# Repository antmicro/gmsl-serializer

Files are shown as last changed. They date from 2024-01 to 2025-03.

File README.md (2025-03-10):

# GMSL Serializer Board

Copyright (c) 2023-2025 [Antmicro](https://www.antmicro.com)

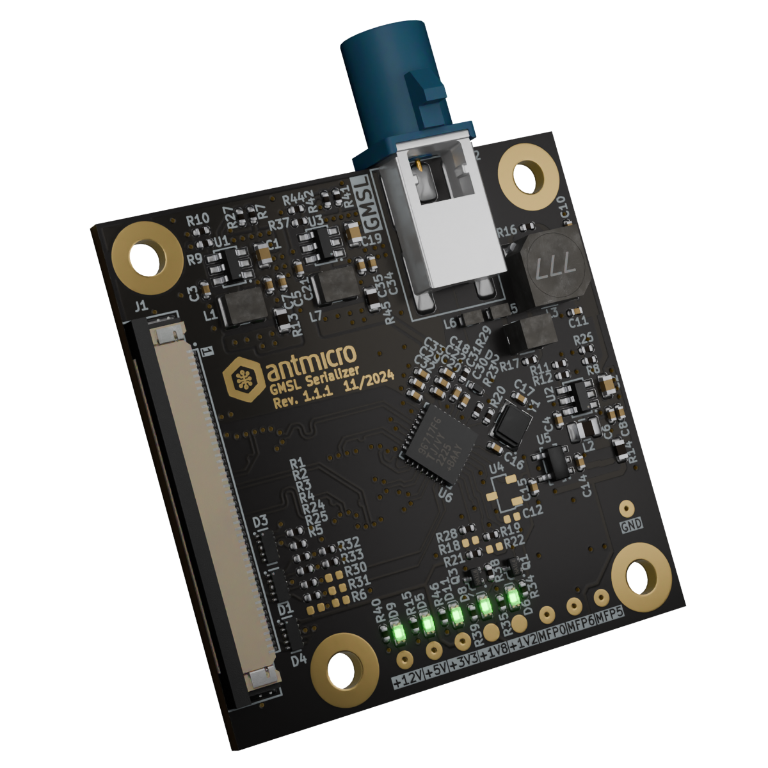
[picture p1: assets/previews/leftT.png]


## Overview

This project contains open hardware design files for the GMSL Serializer Board.
This board accepts MIPI CSI-2 signals from Antmicro's 50-pin FFC video interface and transmits the video data over GMSL2.
The GMSL Serializer Board is powered over GMSL coaxial cable.

The design files were prepared in KiCad 8.

## Key features

* Input: 4-lane MIPI CSI-2 interface on a 50-pin Antmicro Dual Camera connector
* Output: GMSL2 interface exposed on a FAKRA connector
* PoC filter for sinking power from the GMSL coaxial cable

## Project structure

The main project directory contains KiCad PCB project files, a LICENSE, and a README.
The remaining files are stored in the following directories:

* `doc` - contains schematics
* `assets` - contains visual assets for showcasing the board on Antmicro [Open Hardware Portal](https://openhardware.antmicro.com)

## Licensing

This project is published under the [Apache-2.0](LICENSE) license.

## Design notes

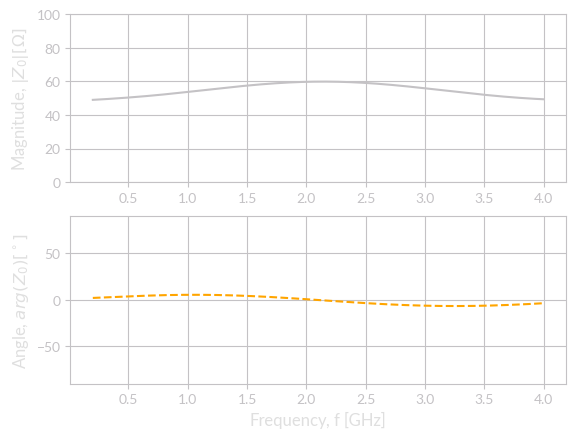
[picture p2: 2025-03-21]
assets/si/GMSL_Connector_SIO_P/Z_1.png

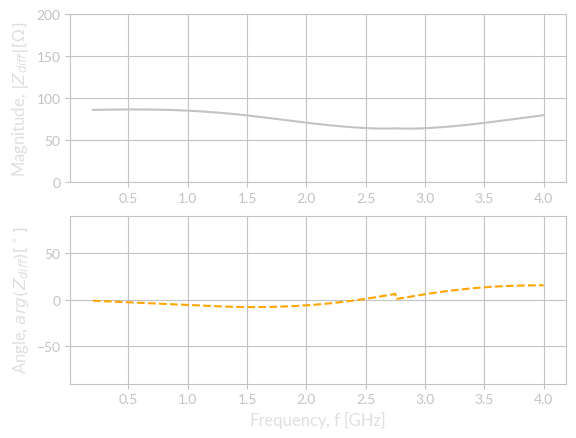
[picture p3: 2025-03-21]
assets/si/CSI_Connector_CSI.D1_Diff/Z_diff.png

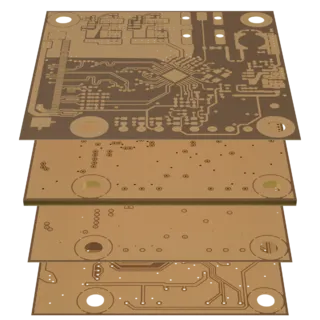
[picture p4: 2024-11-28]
assets/previews/layer1_thumbnail.webp

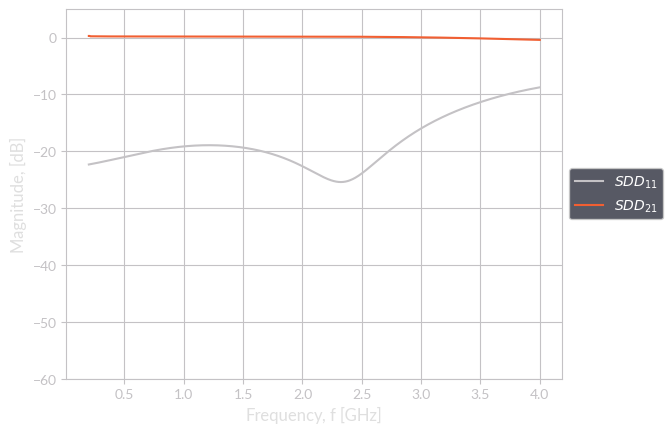
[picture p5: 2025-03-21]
assets/si/CSI_Connector_CSI.D0_Diff/SDD_Diff.png

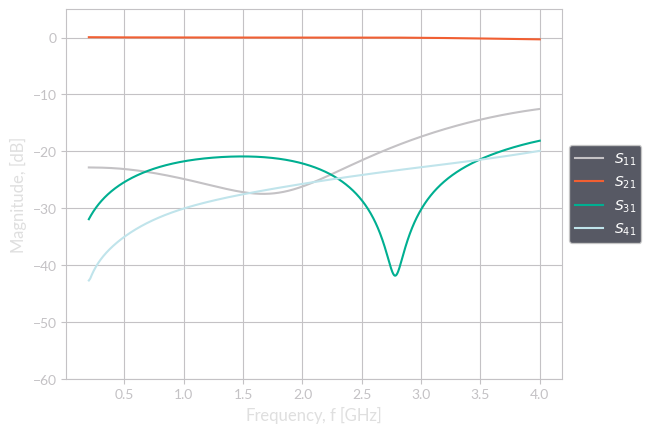
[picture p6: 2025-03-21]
assets/si/CSI_Connector_CSI.D0_Diff/S_x1.png

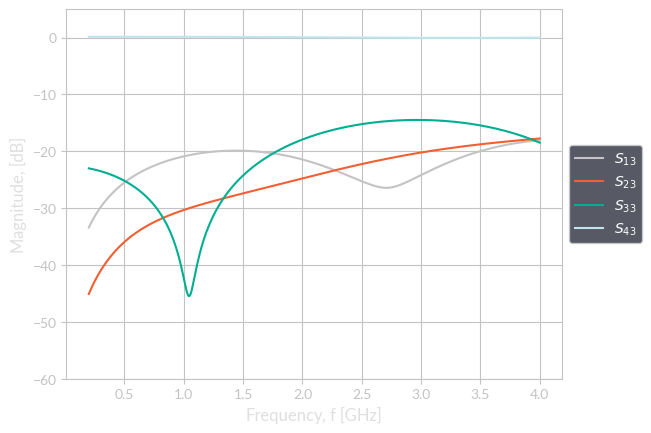
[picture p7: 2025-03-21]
assets/si/CSI_Connector_CSI.CLK_Diff/S_x3.png

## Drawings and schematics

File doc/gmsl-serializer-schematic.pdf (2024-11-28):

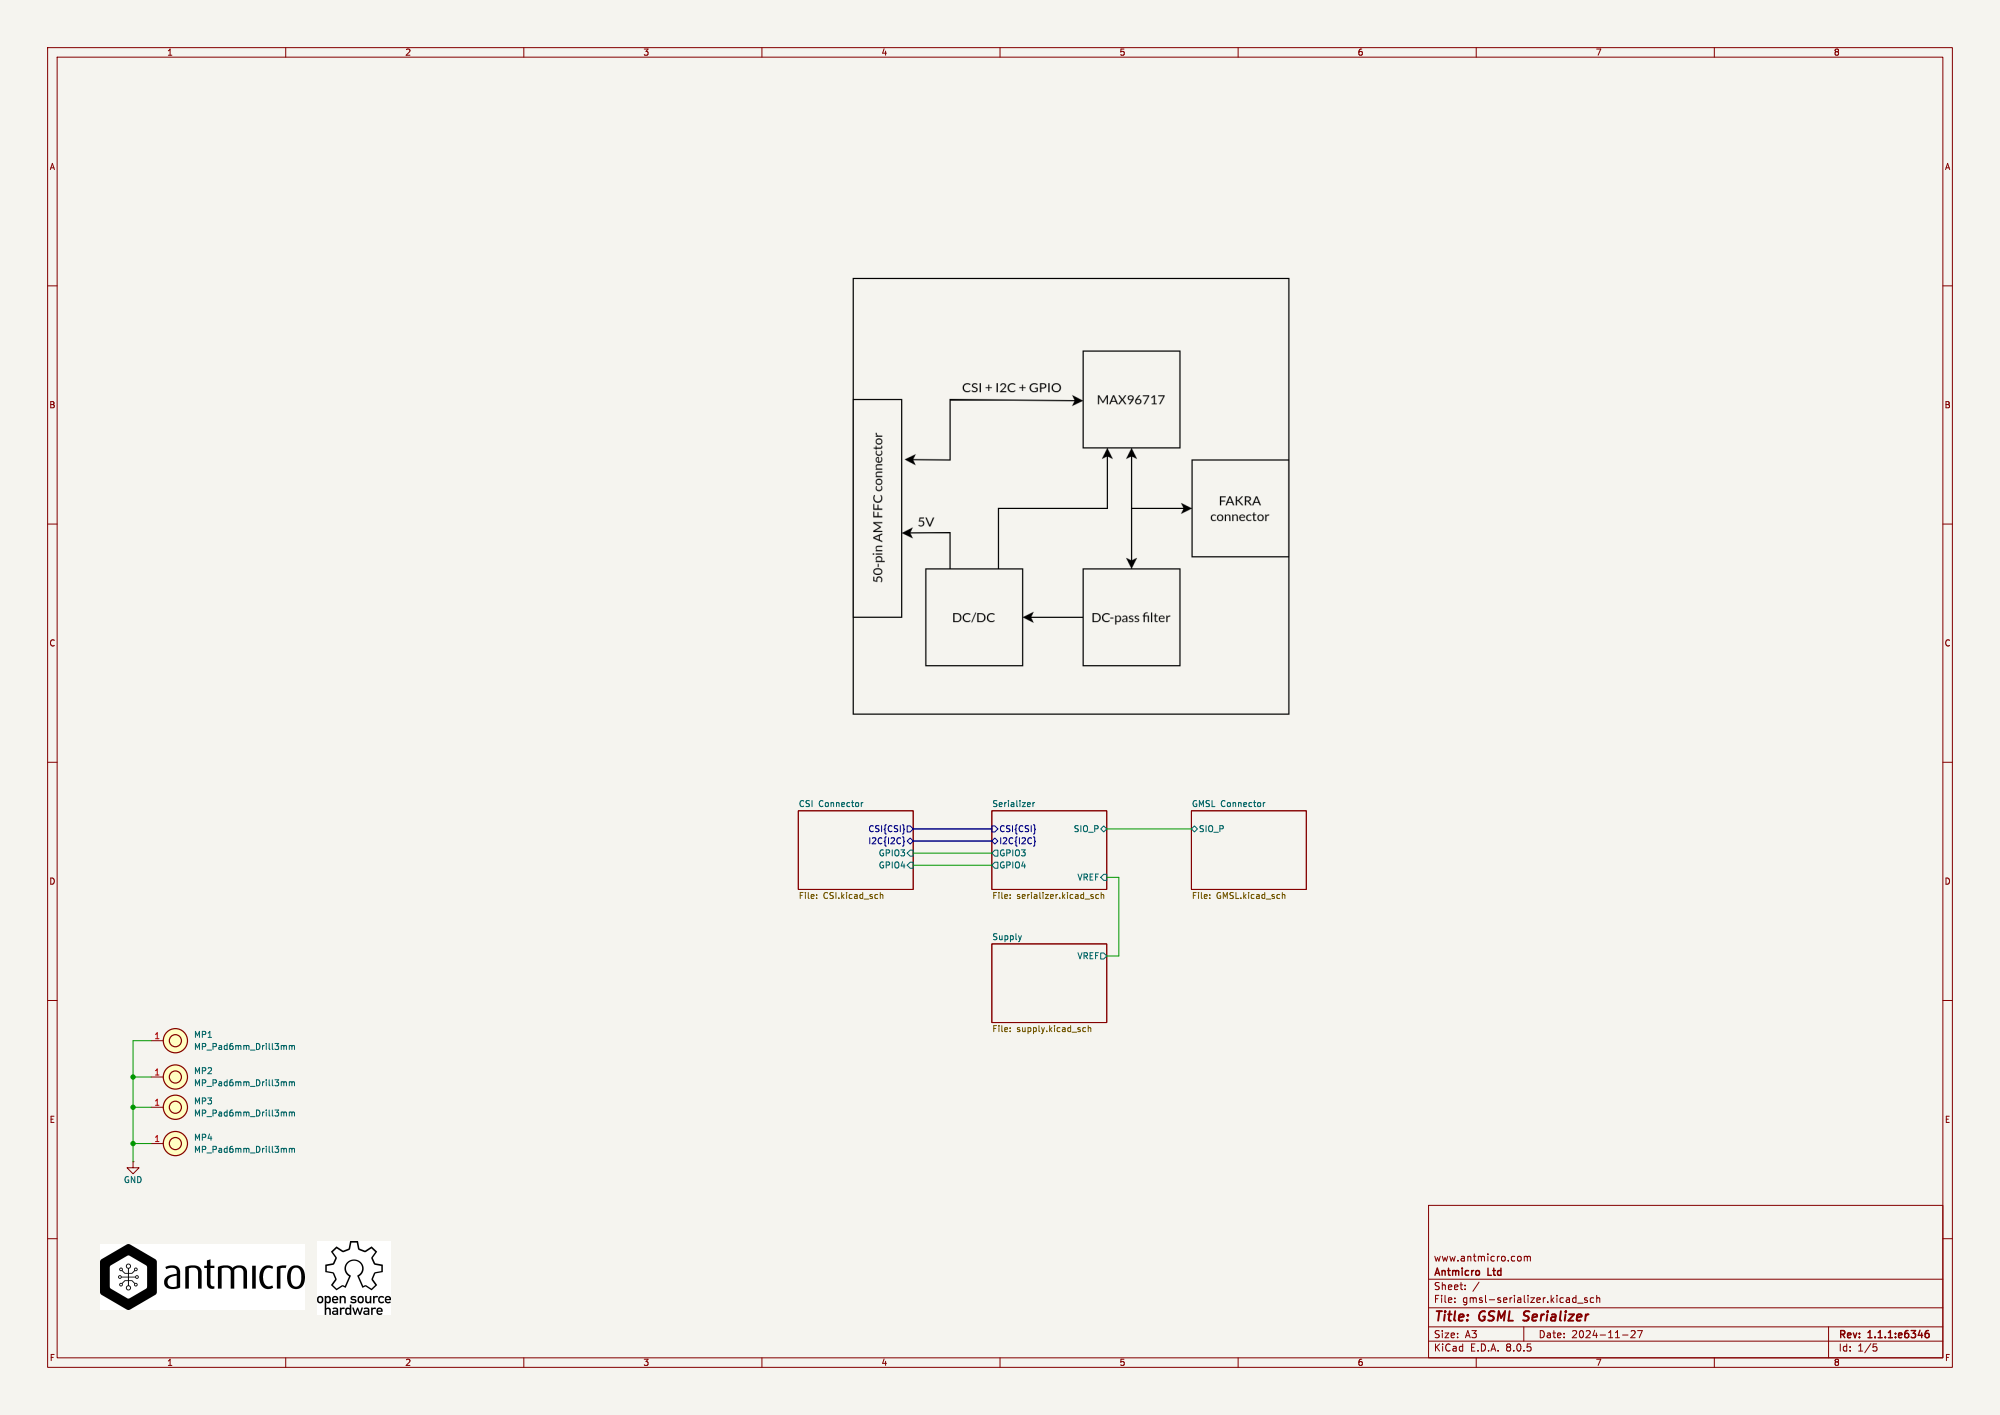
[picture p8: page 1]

I2C{I2C} GPIO4 GPIO3 CSI Connector File: CSI.kicad_sch

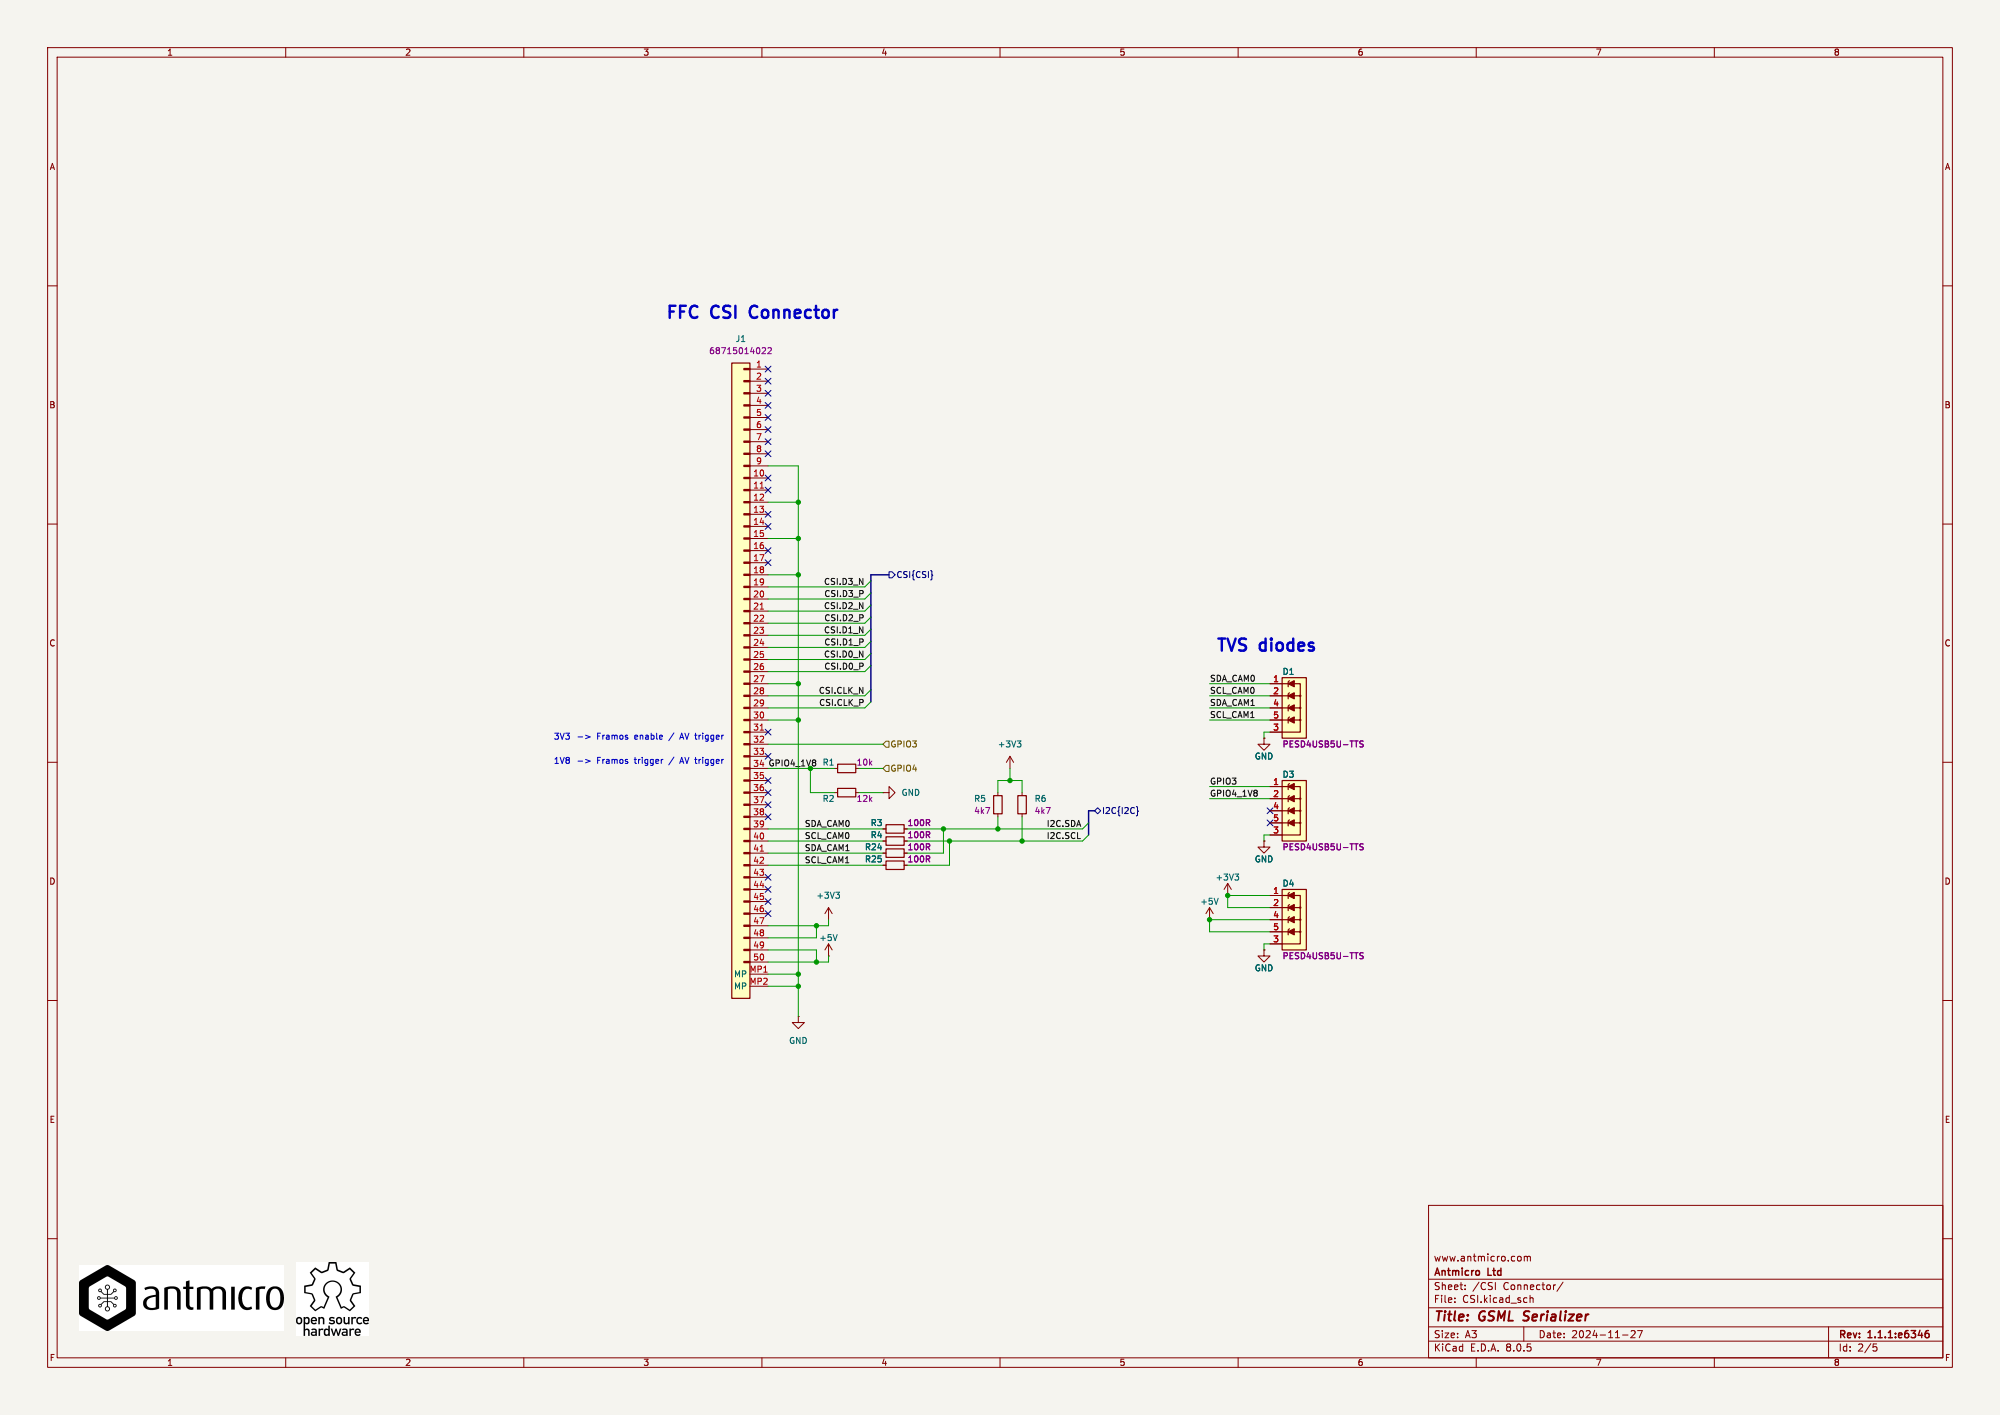
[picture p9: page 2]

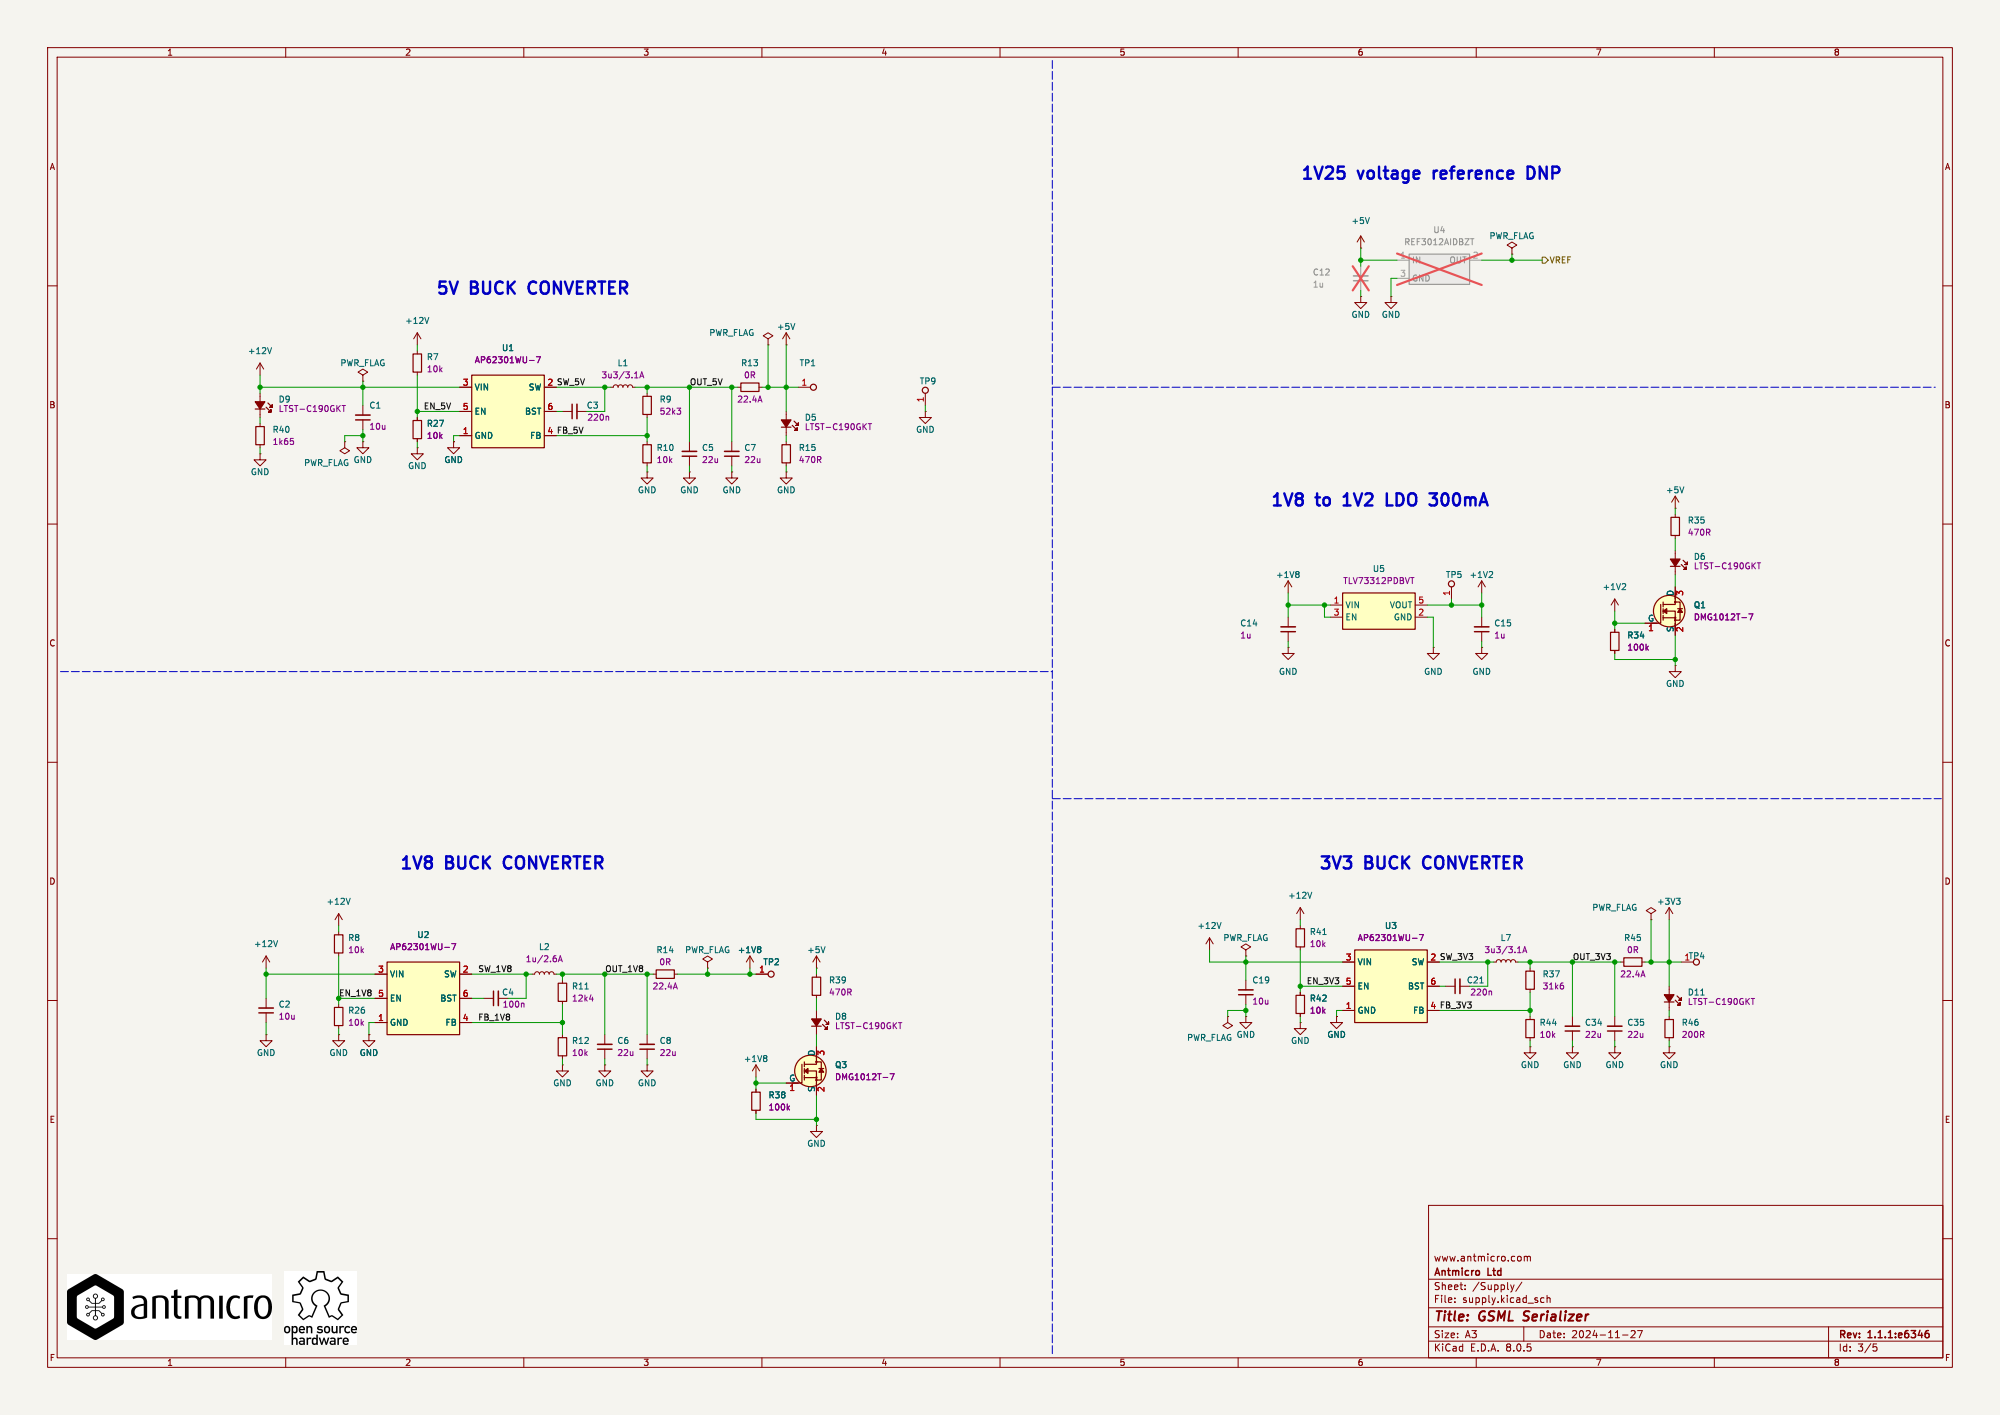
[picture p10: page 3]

1 TP5 +1V2 VIN 1 GND 2 EN 3 VOUT 5 U5 TLV73312PDBVT GND

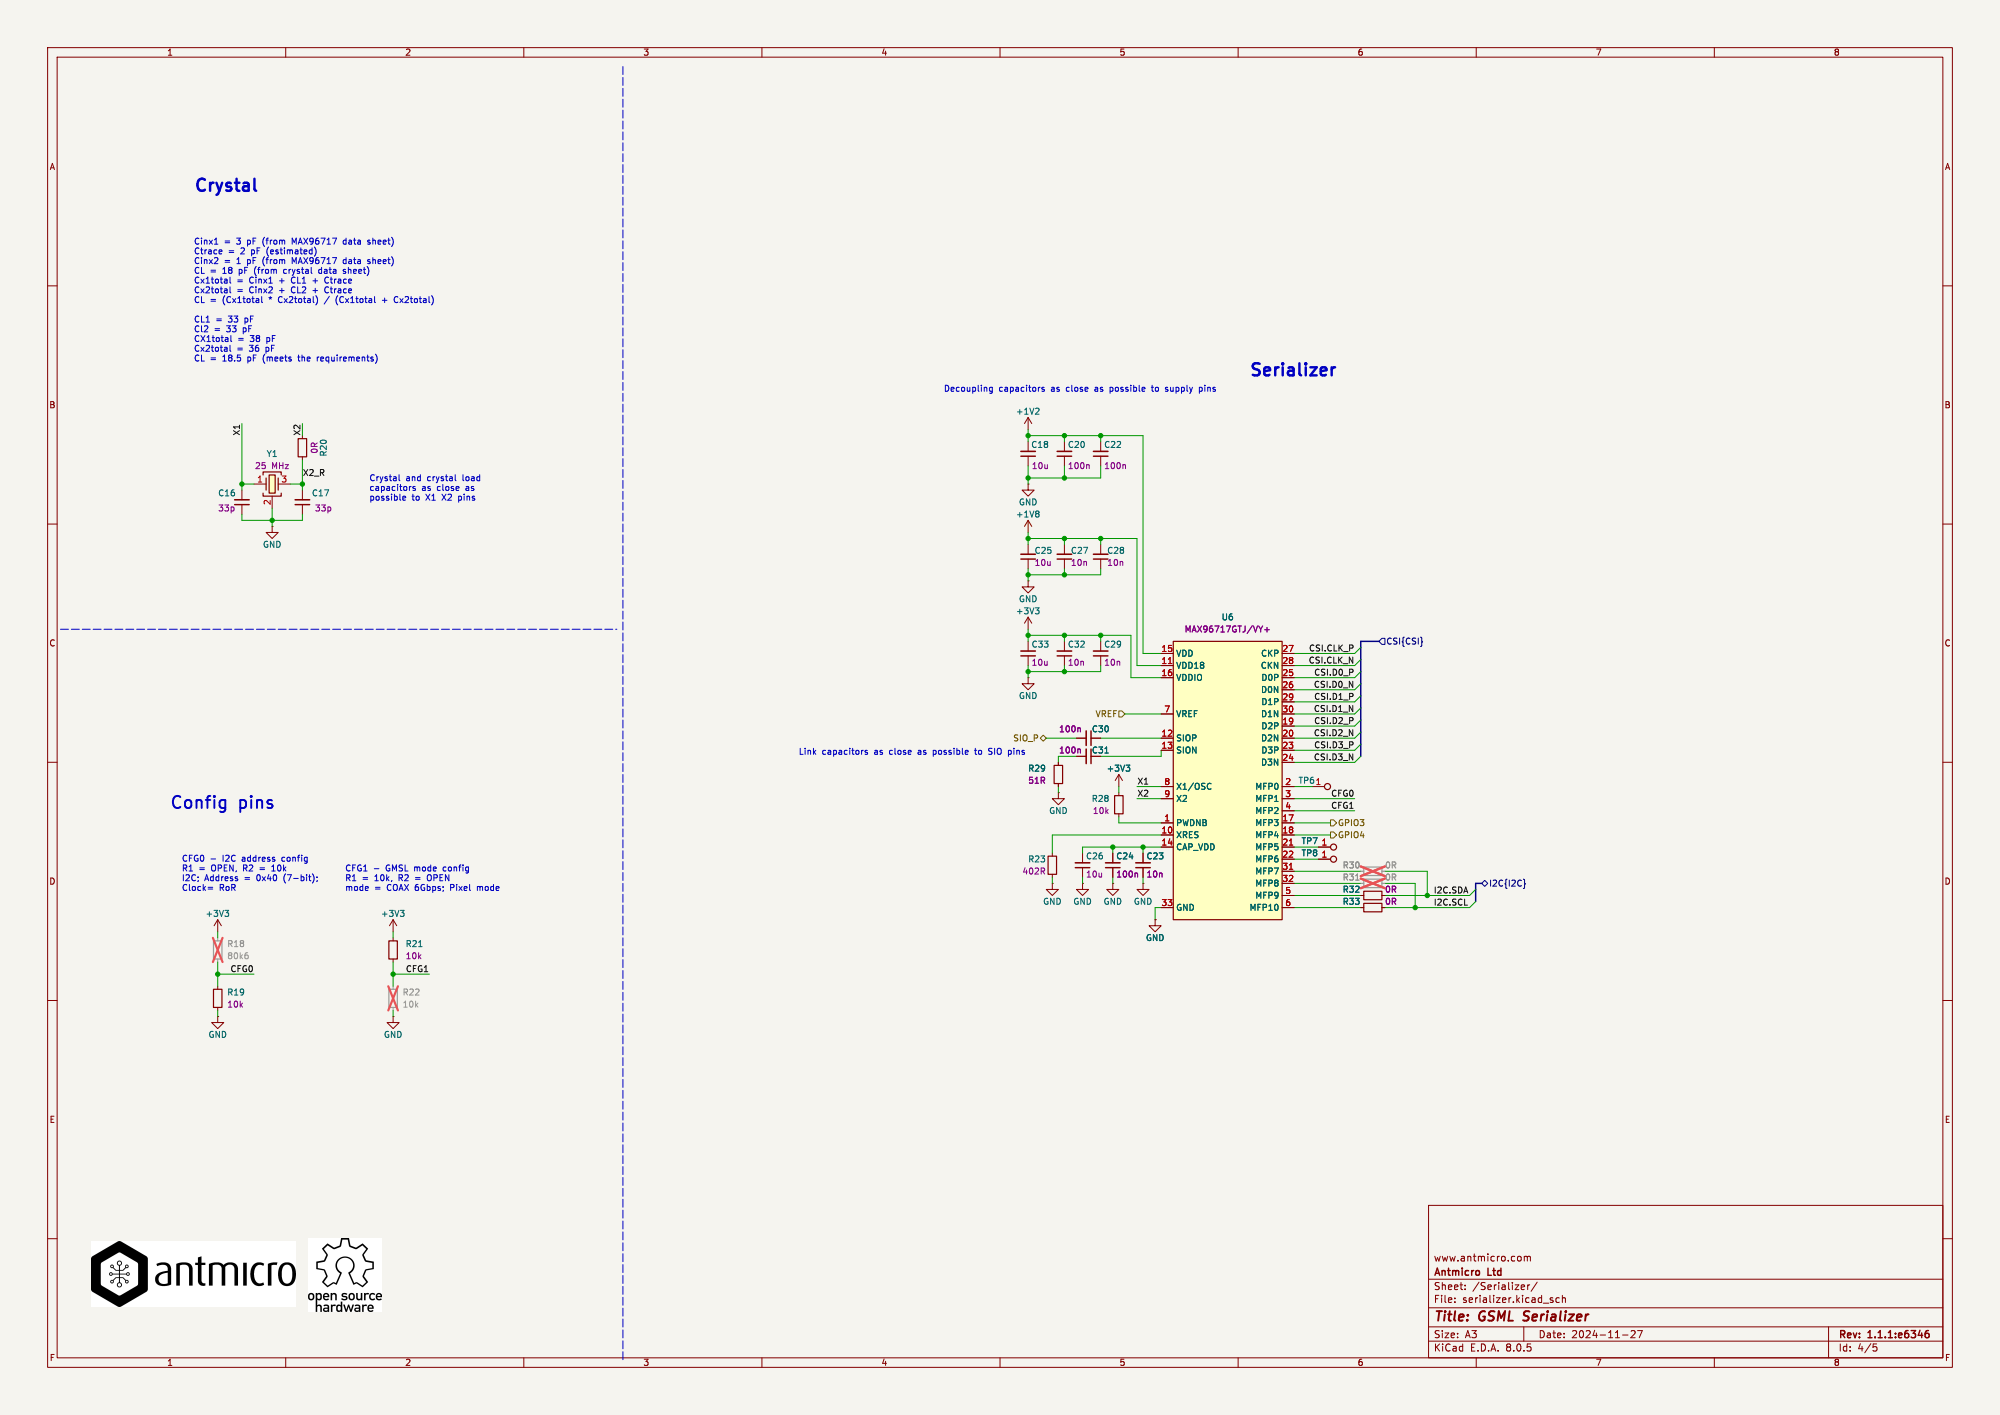
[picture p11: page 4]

Crystal and crystal load

X1 CFG1 - GMSL mode config R1 = 10k, R2 = OPEN mode = COAX 6Gbps; Pixel mode

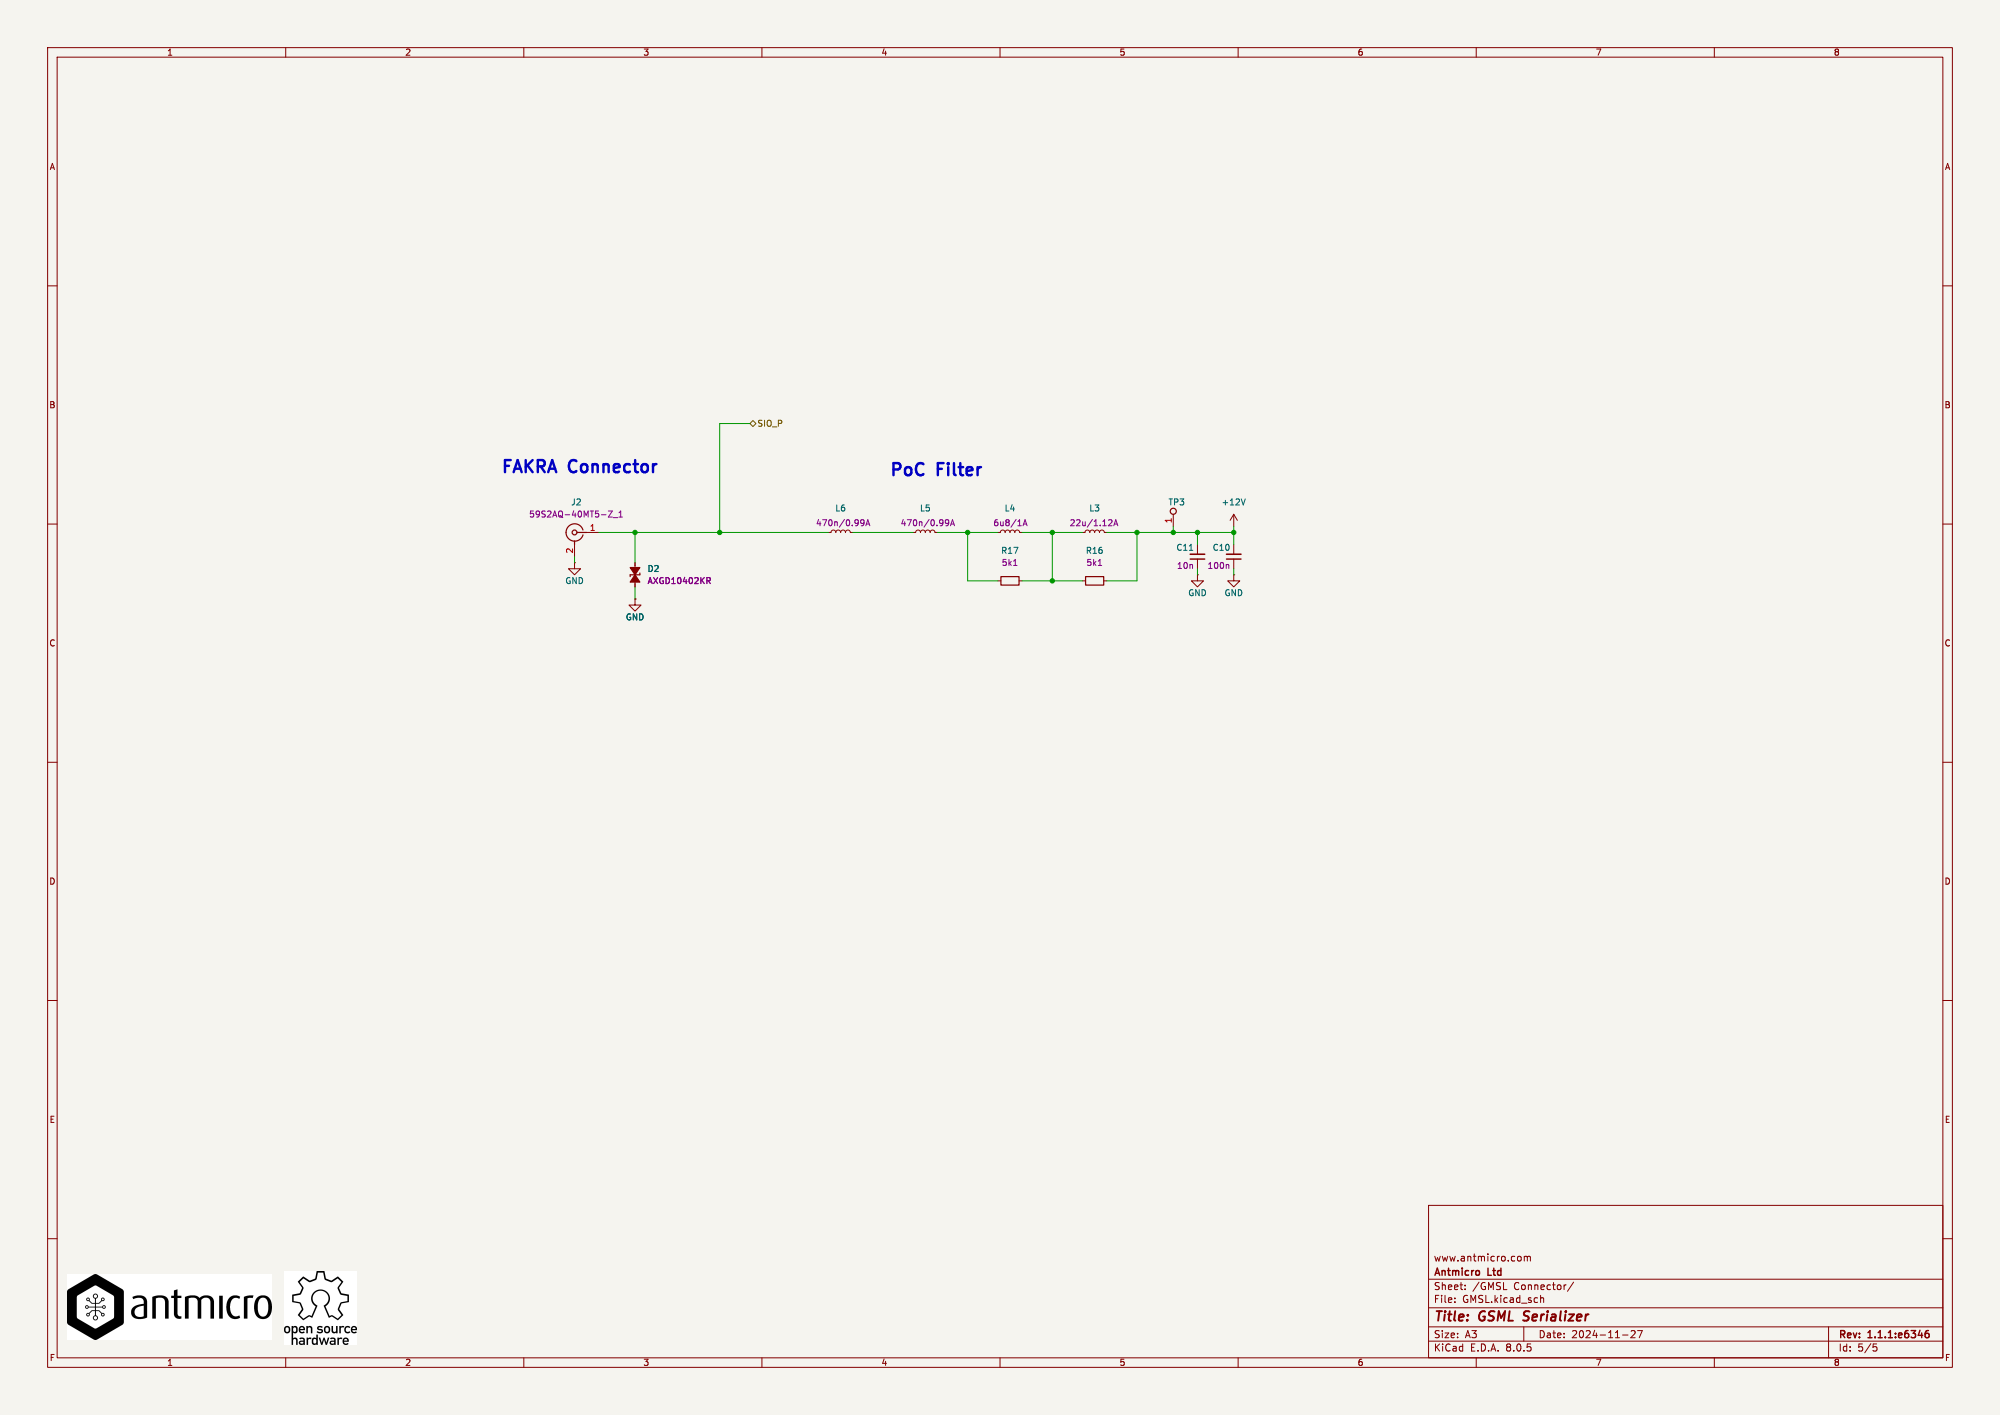
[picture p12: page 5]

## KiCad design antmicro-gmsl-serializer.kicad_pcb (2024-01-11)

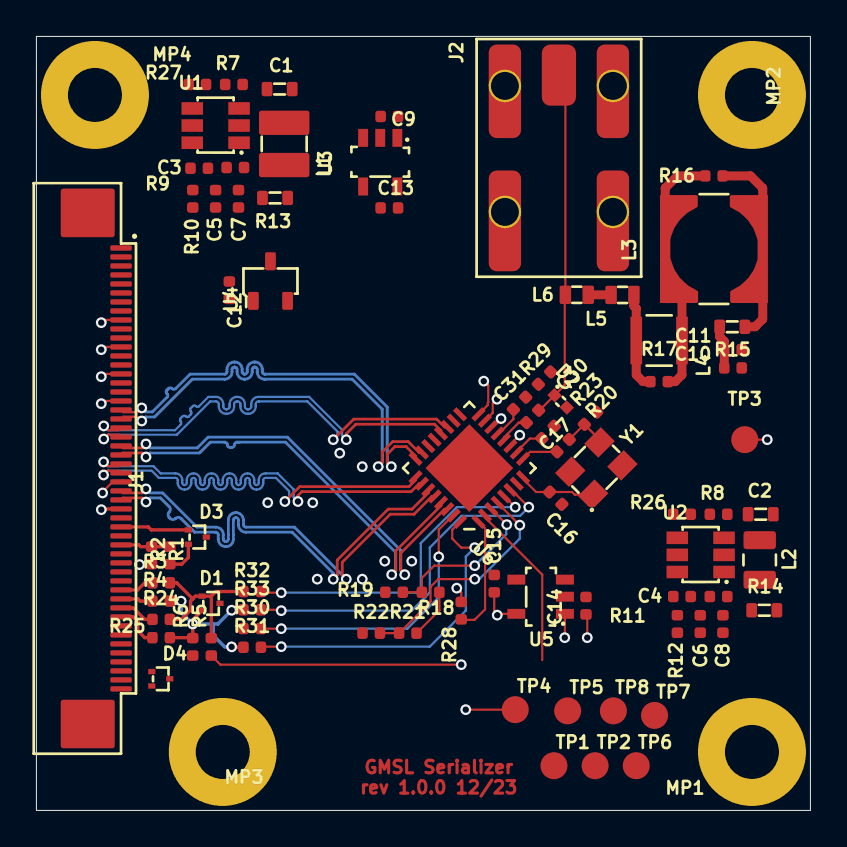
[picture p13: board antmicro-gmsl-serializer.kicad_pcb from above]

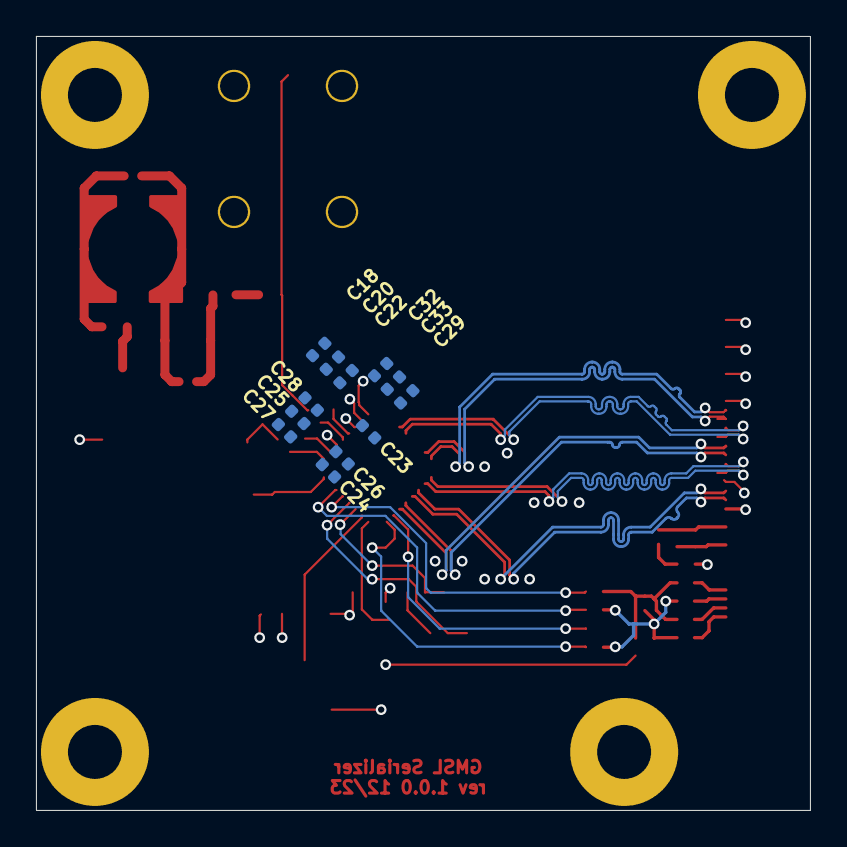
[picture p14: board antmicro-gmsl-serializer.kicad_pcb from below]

Board: 4 copper layers, 43.0 x 43.0 mm, 95 parts (12 on the bottom side), 60 nets.

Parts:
C1, C2: C_10u_25V_0603; C_0603_1608Metric
C3: C_220n_0402; C_0402_1005Metric
C4, C10, C20, C22, C24, C30, C31: C_100n_0402; C_0402_1005Metric
C5, C6, C7, C8: C_22u_0402; C_0402_1005Metric
C9, C12, C13, C14, C15: C_1u_16V_0402; C_0402_1005Metric
C11, C23, C27, C28, C29, C32: C_10n_0402; C_0402_1005Metric
C16, C17: C_33p_0402; C_0402_1005Metric
C18, C25, C26, C33: C_10u_0402; C_0402_1005Metric
D1, D3, D4: TPD2E009_SOT-9X3; SOT-723
D2: AXGD10402KR; D_0402_1005Metric
J1: Conn_FFC_WE_68715014022; Conn_FFC_WE_68715014x22
J2: Conn_FAKRA_2FAI-NZSP-PCBB6; Conn_FAKRA_59S2AQ-40MT5-Z_1
L1: L_3u3_3.1A_Bourns-SRP3212A; L_Bourns-SRP3212A
L2: L_1u_2.6A_0806; L_0806_2016Metric
L3: L_22u_1.12A_Coilcraft-MSS6132T; L_Coilcraft-MSS6132T
L4: L_6u8_1A_Coilcraft-1210POC; L_Coilcraft-1210POC
L5, L6: L_470n_1A_Coilcraft-PFL1609; L_Coilcraft-PFL1609
MP1, MP2, MP3, MP4: MP_Pad6mm_Drill3mm
R1, R7, R8, R10, R12, R19, R22, R26, R27, R28: R_10k_0402; R_0402_1005Metric
R2: R_12k_0402; R_0402_1005Metric
R3, R4, R24, R25: R_100R_0402; R_0402_1005Metric
R5, R6: R_4k7_0402; R_0402_1005Metric
R9: R_52k3_0402; R_0402_1005Metric
R11: R_12k4_0402; R_0402_1005Metric
R13, R14, R15: R_0R_22.4A_0603; R_0603_1608Metric
R16, R17: R_5k1_0402; R_0402_1005Metric
R18, R21: R_80k6_0402; R_0402_1005Metric
R20, R30, R31, R32, R33: R_0R_0402; R_0402_1005Metric
R23: R_402R_0402; R_0402_1005Metric
R29: R_51R_0402; R_0402_1005Metric
TP1, TP2, TP3, TP4, TP5, TP6, TP7, TP8: TP_1.5mm_SMD; TP_SMD_1.5mm
U1, U2: AP62301_TSOT; TSOT23-6
U3: NCP163ASN330T1G; SOT-23-5
U4: REF3012AIDBZT; SOT-23-3
U5: TLV73312PDBVT; SOT-23-5
U6: MAX9295A; QFN-32-1EP_5x5mm
Y1: Resonator_25MHz_ABM8G; Oscillator_SMD_Geyer_KX-7-4Pin_3.2x2.5mm

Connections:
+1V2: C15.2, C18.2, C20.2, C22.2, TP5.1, U5.5 (VOUT), U6.15 (VDD)
+1V8: C14.2, C25.2, C27.2, C28.2, R14.2, TP2.1, U5.1 (VIN), U5.3 (EN), U6.11 (VDD_1.8V)
+3V3: C13.2, C29.2, C32.2, C33.2, D4.1, J1.47, J1.48, R5.2, R6.2, R28.2, TP4.1, U3.5 (VOUT), U6.16 (VDDIO)
+5V: C9.2, C12.2, D4.2, J1.49, J1.50, R13.2, TP1.1, U3.1 (VIN), U3.3 (EN), U4.1 (IN)
+12V: C1.2, C2.2, C10.2, C11.2, R7.2, R8.2, R15.1, TP3.1, U1.3 (VIN), U2.3 (VIN)
/Connectors/SCL_CAM0: J1.40, R4.1
/Connectors/SCL_CAM1: J1.42, R25.1
/Connectors/SDA_CAM0: J1.39, R3.1
/Connectors/SDA_CAM1: J1.41, R24.1
/Serializer/CFG0: R18.1, R19.2, U6.3 (MFP1/CFG0)
/Serializer/CFG1: R21.1, R22.2, U6.4 (MFP2/CFG1)
/Serializer/VDDIO: R18.2, R21.2
/Serializer/X1: C16.2, U6.8 (X1/OSC), Y1.1
/Serializer/X2: R20.2, U6.9 (X2)
/Serializer/X2_R: C17.2, R20.1, Y1.3
/Supply/EN_1V8: R8.1, R26.2, U2.5 (EN)
/Supply/EN_5V: R7.1, R27.2, U1.5 (EN)
/Supply/FB_1V8: R11.1, R12.2, U2.4 (FB)
/Supply/FB_5V: R9.1, R10.2, U1.4 (FB)
/Supply/OUT_1V8: C6.2, C8.2, L2.2, R11.2, R14.1
/Supply/OUT_5V: C5.2, C7.2, L1.2, R9.2, R13.1
/Supply/SW_1V8: C4.2, L2.1, U2.2 (SW)
/Supply/SW_5V: C3.2, L1.1, U1.2 (SW)
CSI_CLK_N: J1.28, U6.28 (CK_N)
CSI_CLK_P: J1.29, U6.27 (CK_P)
CSI_D0_N: J1.25, U6.26 (D0_N)
CSI_D0_P: J1.26, U6.25 (D0_P)
CSI_D1_N: J1.23, U6.30 (D1_N)
CSI_D1_P: J1.24, U6.29 (D1_P)
CSI_D2_N: J1.21, U6.20 (D2_N)
CSI_D2_P: J1.22, U6.19 (D2_P)
CSI_D3_N: J1.19, U6.24 (D3_N)
CSI_D3_P: J1.20, U6.23 (D3_P)
GND: C1.1, C2.1, C5.1, C6.1, C7.1, C8.1, C9.1, C10.1, C11.1, C12.1, C13.1, C14.1, C15.1, C16.1, C17.1, C18.1, C20.1, C22.1, C23.1, C24.1, C25.1, C26.1, C27.1, C28.1, C29.1, C32.1, C33.1, D1.3, D2.2, D3.3, D4.3, J1.9, J1.12, J1.15, J1.18, J1.27, J1.30, J1.MP1 (MP), J1.MP2 (MP), J2.2, J2.3, J2.4, J2.5, MP1.1, MP2.1, MP3.1, MP4.1, R2.2, R10.1, R12.1, R19.1, R22.1, R23.1, R26.1, R27.1, R29.1, U1.1 (GND), U2.1 (GND), U3.2 (GND), U4.3 (GND), U5.2 (GND), U6.33 (GND), Y1.2 (SH), Y1.4 (SH)
GPIO3: D3.1, J1.32, U6.17 (MFP3)
GPIO4: D3.2, R1.2, U6.18 (MFP4)
unnamed: C3.1, U1.6 (BST)
unnamed: C4.1, U2.6 (BST)
unnamed: C23.2, C24.2, C26.2, U6.14 (CAP_VDD)
unnamed: C30.1, U6.12 (SIO_P)
unnamed: C31.1, U6.13 (SIO_N)
unnamed: C31.2, R29.2
unnamed: J1.34, R1.1, R2.1
unnamed: L3.1, R15.2, R16.1
unnamed: L3.2, L4.1, R16.2, R17.1
unnamed: L4.2, L5.1, R17.2
unnamed: L5.2, L6.1
unnamed: R23.2, U6.10 (XRES)
unnamed: R28.1, U6.1 (PWDNB)
unnamed: R30.2, U6.31 (MFP7)
unnamed: R31.2, U6.32 (MFP8)
unnamed: R32.2, U6.5 (MFP9)
unnamed: R33.2, U6.6 (MFP10)
unnamed: TP6.1, U6.2 (MFP0)
unnamed: TP7.1, U6.21 (MFP5)
unnamed: TP8.1, U6.22 (MFP6)
SCL: D1.2, R4.2, R6.1, R25.2, R31.1, R33.1
SDA: D1.1, R3.2, R5.1, R24.2, R30.1, R32.1
SIO_P: C30.2, D2.1, J2.1, L6.2
VREF: U4.2 (OUT), U6.7 (VREF)

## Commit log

2024-01-11 Add initial project
    [antmicro-gmsl-serializer.kicad_pcb, antmicro-gmsl-serializer.kicad_sch]
2024-01-11 Add 50 pin FFC cSI connector
    [antmicro-gmsl-serializer.kicad_sch, connectors.kicad_sch]
2024-01-11 Add PoC, 5V converter, 1V8 converter
    [antmicro-gmsl-serializer.kicad_sch, serializer.kicad_sch, supply.kicad_sch]
2024-01-11 Add 1V8 to 1V2 LDO
    [antmicro-gmsl-serializer.kicad_sch, supply.kicad_sch]
2024-01-11 Change revision on schematic to 1.0.0
    [antmicro-gmsl-serializer.kicad_sch, connectors.kicad_sch, serializer.kicad_sch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]
2024-01-11 Add FAKRA connector
    [antmicro-gmsl-serializer.kicad_sch, connectors.kicad_sch]
2024-01-11 Add serializer supply filtration
    [serializer.kicad_sch]
2024-01-11 [WiP]:Add serializer signals and decoupling capacitors
    [antmicro-gmsl-serializer.kicad_sch, connectors.kicad_sch, serializer.kicad_sch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]
2024-01-11 Add cfg pins handling
    [antmicro-gmsl-serializer.kicad_sch, serializer.kicad_sch]
2024-01-11 Add crystal to the serializer chip
    [antmicro-gmsl-serializer.kicad_sch, serializer.kicad_sch]
2024-01-11 Add 5V -> 3V3 LDO to supply section
    [antmicro-gmsl-serializer.kicad_sch, supply.kicad_sch]
2024-01-11 Change VDDIO to 3V3
    [antmicro-gmsl-serializer.kicad_sch, serializer.kicad_sch]
2024-01-11 Add i2c and gpio triggers
    [antmicro-gmsl-serializer.kicad_sch, connectors.kicad_sch, serializer.kicad_sch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]
2024-01-11 Add resistor selectable i2c
    [antmicro-gmsl-serializer.kicad_sch, connectors.kicad_sch, serializer.kicad_sch]
2024-01-11 Add testpoints to unused MF pins
    [antmicro-gmsl-serializer.kicad_sch, serializer.kicad_sch]
2024-01-11 Add 2V5 VREF
    [antmicro-gmsl-serializer.kicad_sch, serializer.kicad_sch, supply.kicad_sch]
2024-01-11 Add block diagram to schematic
    [antmicro-gmsl-serializer.kicad_sch, supply.kicad_sch]
2024-01-11 Add low-capacitance TVS to serial output
    [antmicro-gmsl-serializer.kicad_sch, connectors.kicad_sch, serializer.kicad_sch]
2024-01-11 Add I2C protection
    [antmicro-gmsl-serializer.kicad_sch, connectors.kicad_sch, serializer.kicad_sch]
2024-01-11 Anotate components and fix ERC errors and warnings
    [antmicro-gmsl-serializer.kicad_sch, connectors.kicad_sch, serializer.kicad_sch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]
2024-01-11 Import layer stack, add mounting points
    [antmicro-gmsl-serializer.kicad_pcb, antmicro-gmsl-serializer.kicad_sch]
2024-01-11 Draw board outline, place MPs and 50pin conn
    [antmicro-gmsl-serializer.kicad_pcb]
2024-01-11 Route CSI lines
    [antmicro-gmsl-serializer.kicad_pcb]
2024-01-11 Tune CSI lines
    [antmicro-gmsl-serializer.kicad_pcb]
2024-01-11 Add stiching vias and GND planes
    [antmicro-gmsl-serializer.kicad_pcb]
2024-01-11 Place and route PoC filter
    [antmicro-gmsl-serializer.kicad_pcb]
2024-01-11 Place and route chip decoupling caps and oscillator
    [antmicro-gmsl-serializer.kicad_pcb]
2024-01-11 Place and route DC converters
    [antmicro-gmsl-serializer.kicad_pcb]
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2024-01-11 Implement changes suggested in design review to schematics
    [antmicro-gmsl-serializer.kicad_sch, connectors.kicad_sch, serializer.kicad_sch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]
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2024-01-11 Route I2C
    [antmicro-gmsl-serializer.kicad_pcb]
2024-01-11 Route 12V to 5V DC converter
    [antmicro-gmsl-serializer.kicad_sch, connectors.kicad_sch]
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2024-01-11 Allign schematic components
    [serializer.kicad_sch]
2024-01-11 Remove R15 and anotate schematic
    [antmicro-gmsl-serializer.kicad_sch, supply.kicad_sch]
2024-01-11 Remove leftover ERC exclusions
    [connectors.kicad_sch]
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2024-01-11 [#53377] Add LDO config register addresses to schematic
    [serializer.kicad_sch]
2024-01-11 [#53377] Rearange supply schematic
    [supply.kicad_sch]
2024-01-11 [#53377] Mark 1V25 reference as DNP
    [supply.kicad_sch]
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2024-06-21 [#55438] Add LED indicators to schematics
    [connectors.kicad_sch, gmsl-serializer.kicad_sch, serializer.kicad_sch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]
2024-06-21 [#55438] Place LED indicators on PCB
    [connectors.kicad_sch, gmsl-serializer.kicad_sch, serializer.kicad_sch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]
2024-06-24 [#55438] Add GND testpoint
    [supply.kicad_sch]
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2024-10-04 [#66847] Make schematic hierarchical
    [CSI.kicad_sch, GMSL.kicad_sch, gmsl-serializer.kicad_sch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]
2024-10-04 [#66847] Serializer chip: MAX9295A -> MAX96717
    [serializer.kicad_sch]
2024-10-07 [#66847] unDNP pullups on I2C; update pcb from sch
    [CSI.kicad_sch, GMSL.kicad_sch, serializer.kicad_sch]
2024-10-07 [#66847] Update DNP style; Update from lib; Fix CSI bus definition
    [GMSL.kicad_sch, gmsl-serializer.kicad_sch, serializer.kicad_sch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]
2024-10-07 [#66847] Change 3V3 LDO; Update L3 footprint
    [supply.kicad_sch]
2024-10-07 [#66847] Start improving CSI layout
    [gmsl-serializer.kicad_sch, supply.kicad_sch]
2024-10-08 [#66847] Bump date&rev; Clean ERC
    [CSI.kicad_sch, GMSL.kicad_sch, gmsl-serializer.kicad_sch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]
2024-10-08 [#66847] Update config resistors
    [serializer.kicad_sch]
2024-10-08 [#66847] Show MPN insted value; Update description
    [CSI.kicad_sch, GMSL.kicad_sch, supply.kicad_sch]
2024-10-08 [#66847] Update MAX96717 symbol: flip CSI N/P to match symbol standard
    [serializer.kicad_sch]
2024-11-25 [#69177] Update to Kicad 8
    [CSI.kicad_sch, GMSL.kicad_sch, gmsl-serializer.kicad_sch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]
2024-11-25 [#69177] Switched 3V3 suply from LDO to buck converter
    [supply.kicad_sch]
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2024-11-25 [#69177] Solved all DRC problems
    [supply.kicad_sch]
2024-11-27 [#69177] Post review fixes
    [gmsl-serializer.kicad_sch]
2024-11-27 [#69177] Updated assets and PDF schematics
    [CSI.kicad_sch, GMSL.kicad_sch, serializer.kicad_sch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]
2025-03-21 [#74135] Add SI assets
    [Port_0_data.csv, Port_2_data.csv]

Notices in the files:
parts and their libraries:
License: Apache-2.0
